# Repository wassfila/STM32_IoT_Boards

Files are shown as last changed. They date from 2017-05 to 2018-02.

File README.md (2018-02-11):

# STM32_IoT_Boards
* Expansion boards, PCB designs with STM32 chips.
* firmware running mbed-os
* simplest mesh ever with c++ driver libraries, rf-mesh lib using an nrf24l01+ lib

# Progress
* PCBs are under test
* 24 PIO ULN on/off test successfull
* Still no noticed design issues
* Current struggle with the PA3,PA2 ports that do not output the PWM as configured for a default UART
* Sensors node already working fine as an RF-Dongle (sensors not tested yet)
* Soldering order of nrf and bluepill is very important !!! Soldering order strategy required as it is double sided board.

# Git Submodules
* Still struggling with submodules, do not forget either of recursive clone, or manual add of submodule for pilibs

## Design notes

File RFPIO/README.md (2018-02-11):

# design_pcb_eagle

# firmware
* STM32 
* Bluepill as target
* mbed-os

# picpp_control
* Raspberry pi c++ control code that communicates with the Dongle firmware (not this one, rather the one under RFNode) through serial port
* This firmware is expecting RF messages coming from a dongle

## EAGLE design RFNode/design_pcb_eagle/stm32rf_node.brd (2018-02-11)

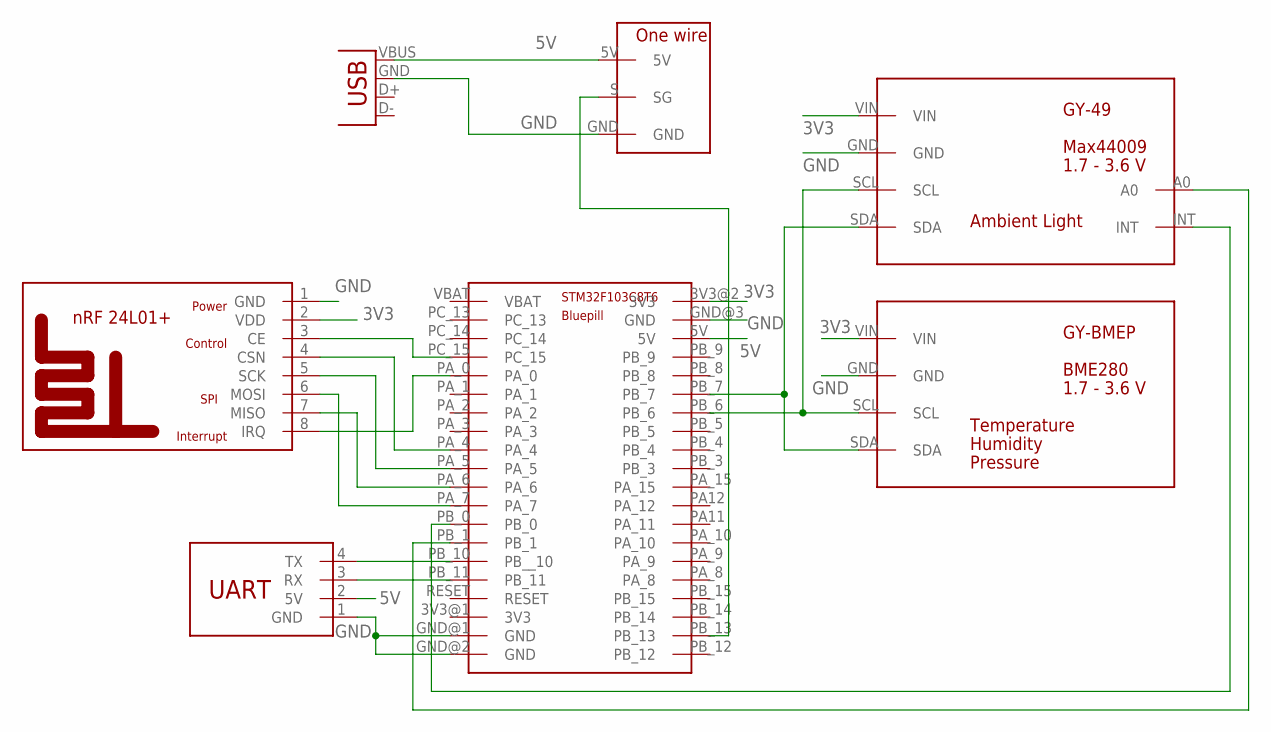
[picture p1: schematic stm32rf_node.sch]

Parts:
U$1: STM32_BLUEPILL
U$2: NRF24L01+REFDESIGNMINI; NRF24L01+REFDESIGN-MINI
U$3: GY-BMEPGY-BMEP-NOHOLE; GY-BMEP-NOHOLE
U$4: GY-49G-49-SURF; GY-49-SURF
U$5: ONE_WIRE'RIGHT'; ONE_WIRE_RIGHT
U$6: UARTMINI; UART-MINI
X1: USB-A-H

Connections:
3V3: U$1.3V3@2 (3V3), U$2.2 (VDD), U$3.VIN, U$4.VIN
5V: U$1.5V, U$5.5V, U$6.2 (5V), X1.VBUS (GND)
GND: U$1.GND@1 (GND), U$1.GND@2 (GND), U$1.GND@3 (GND), U$2.1 (GND), U$3.GND, U$4.GND, U$5.GND, U$6.1 (GND), X1.GND (VBUS)
INT: U$1.PB_0, U$4.INT
unnamed: U$1.PA_7, U$2.6 (MOSI)
unnamed: U$1.PA_6, U$2.7 (MISO)
unnamed: U$1.PA_5, U$2.5 (SCK)
unnamed: U$1.PA_4, U$2.4 (CSN)
unnamed: U$1.PB_1, U$4.A0
unnamed: U$1.PA_0, U$2.8 (IRQ)
unnamed: U$1.PB_10 (PB__10), U$6.4 (TX)
unnamed: U$1.PB_11, U$6.3 (RX)
unnamed: U$1.PB_6, U$3.SCL, U$4.SCL
unnamed: U$1.PB_7, U$3.SDA, U$4.SDA
unnamed: U$1.PC_15, U$2.3 (CE)
unnamed: U$1.PB_13, U$5.S (SG)

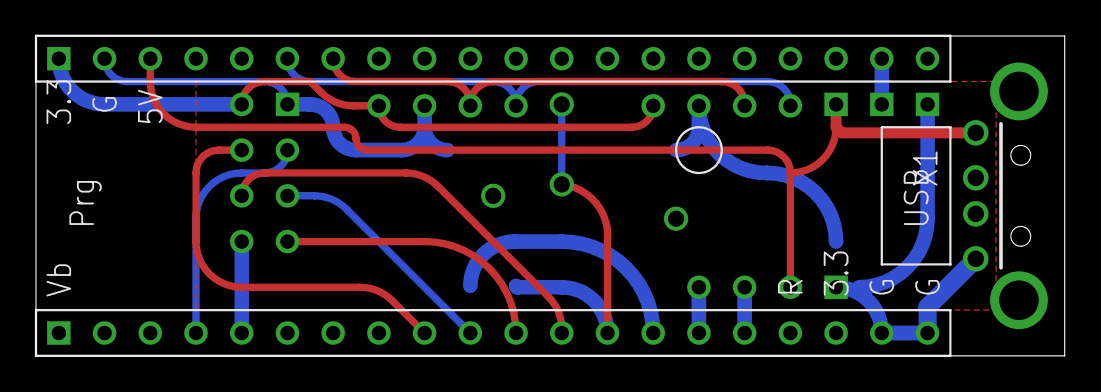
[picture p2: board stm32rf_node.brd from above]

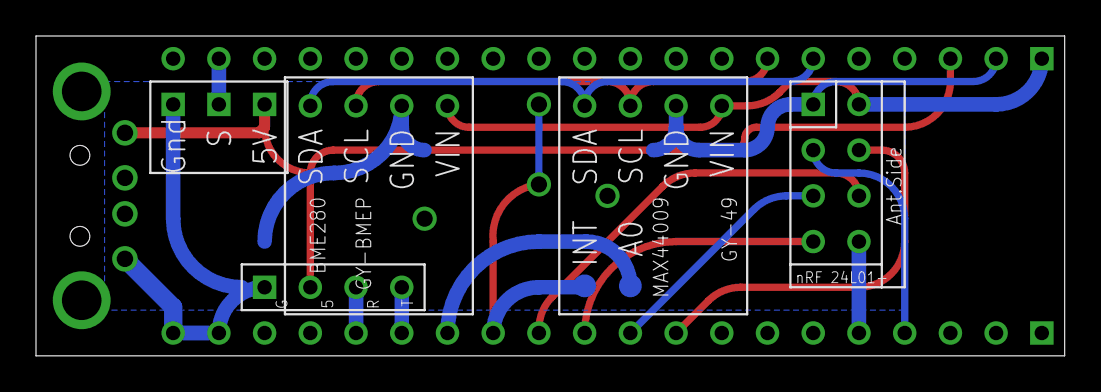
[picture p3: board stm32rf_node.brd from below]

Board: 2 copper layers, 57.1 x 17.8 mm, 7 parts (5 on the bottom side), 16 nets.

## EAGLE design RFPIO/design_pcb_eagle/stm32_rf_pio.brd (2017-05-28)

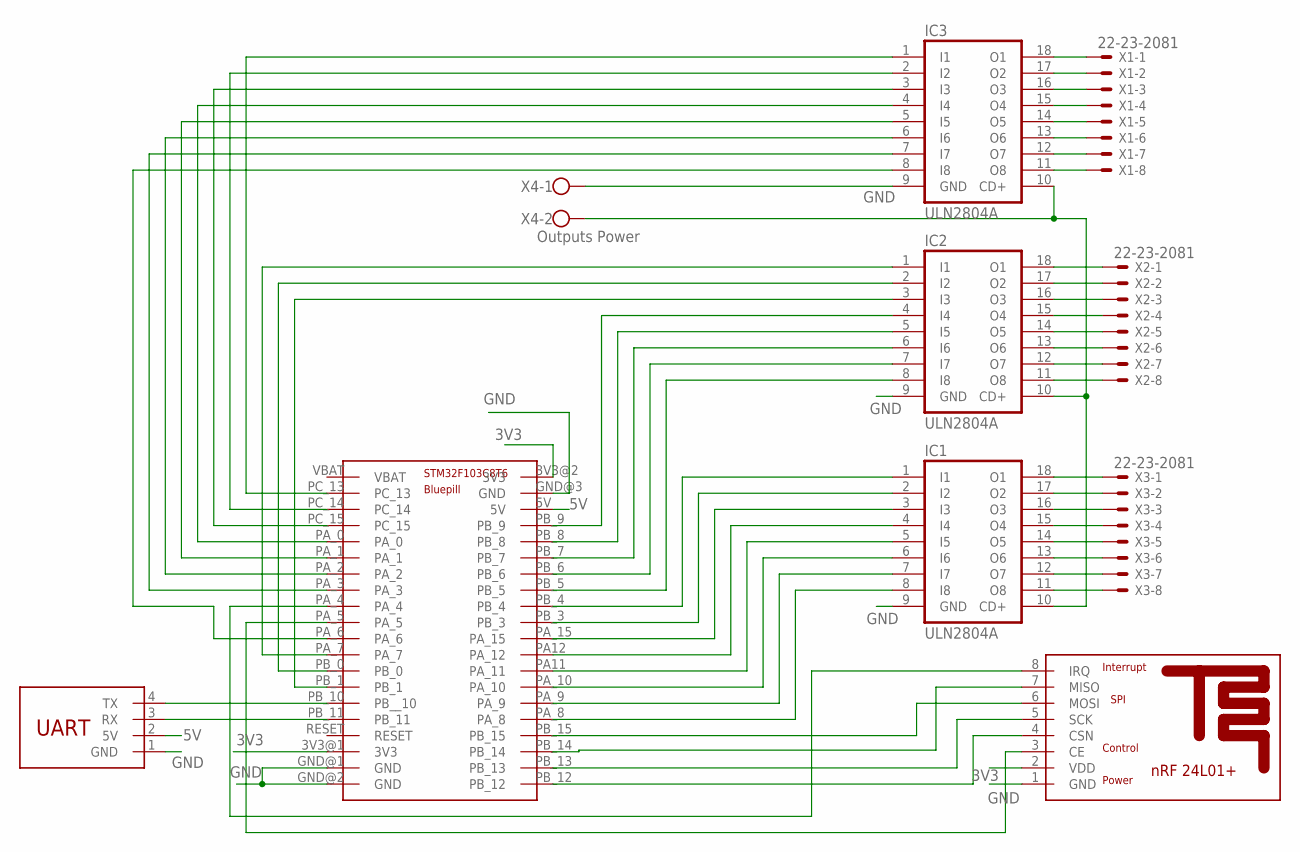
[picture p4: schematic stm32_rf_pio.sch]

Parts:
IC1, IC2, IC3: ULN2804A; DIL18
U$1: STM32_BLUEPILL
U$2: NRF24L01+REFDESIGNMINI; NRF24L01+REFDESIGN-MINI
U$3: UARTMINI; UART-MINI
X1, X2, X3: 22-23-2081
X4: Outputs Power; W237-102

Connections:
3V3: U$1.3V3@1 (3V3), U$1.3V3@2 (3V3), U$2.2 (VDD)
5V: U$1.5V, U$3.2 (5V)
A12: IC1.4 (I4), U$1.PA12 (PA_12)
GND: IC1.9 (GND), IC2.9 (GND), IC3.9 (GND), U$1.GND@1 (GND), U$1.GND@2 (GND), U$1.GND@3 (GND), U$2.1 (GND), U$3.1 (GND), X4.1
HV: IC1.10 (CD+), IC2.10 (CD+), IC3.10 (CD+), X4.2
M11: IC1.8 (I8), U$1.PA_8
M12: IC1.7 (I7), U$1.PA_9
M13: IC1.6 (I6), U$1.PA_10
M14: IC1.5 (I5), U$1.PA11 (PA_11)
M21: IC1.3 (I3), U$1.PA_15
M22: IC1.2 (I2), U$1.PB_3
M23: IC3.6 (I6), U$1.PA_2
M24: IC3.7 (I7), U$1.PA_3
M31: IC1.1 (I1), U$1.PB_4
M32: IC2.8 (I8), U$1.PB_5
M33: IC2.2 (I2), U$1.PB_0
M34: IC2.3 (I3), U$1.PB_1
unnamed: U$1.PB_12, U$2.4 (CSN)
unnamed: U$1.PB_13, U$2.5 (SCK)
unnamed: U$1.PB_14, U$2.7 (MISO)
unnamed: U$1.PB_15, U$2.6 (MOSI)
unnamed: IC2.7 (I7), U$1.PB_6
unnamed: IC2.6 (I6), U$1.PB_7
unnamed: IC2.5 (I5), U$1.PB_8
unnamed: IC2.4 (I4), U$1.PB_9
unnamed: IC2.1 (I1), U$1.PA_7
unnamed: IC3.18 (O1), X1.1
unnamed: IC3.17 (O2), X1.2
unnamed: IC3.16 (O3), X1.3
unnamed: IC3.4 (I4), U$1.PA_0
unnamed: IC3.5 (I5), U$1.PA_1
unnamed: IC3.8 (I8), U$1.PA_6
unnamed: IC3.1 (I1), U$1.PC_13
unnamed: IC3.2 (I2), U$1.PC_14
unnamed: IC3.3 (I3), U$1.PC_15
unnamed: IC3.15 (O4), X1.4
unnamed: IC3.14 (O5), X1.5
unnamed: IC3.13 (O6), X1.6
unnamed: IC3.12 (O7), X1.7
unnamed: IC3.11 (O8), X1.8
unnamed: IC2.18 (O1), X2.1
unnamed: IC2.17 (O2), X2.2
unnamed: IC2.16 (O3), X2.3
unnamed: IC2.15 (O4), X2.4
unnamed: IC2.14 (O5), X2.5
unnamed: IC2.13 (O6), X2.6
unnamed: IC2.12 (O7), X2.7
unnamed: IC2.11 (O8), X2.8
unnamed: IC1.18 (O1), X3.1
unnamed: IC1.17 (O2), X3.2
unnamed: IC1.16 (O3), X3.3
unnamed: IC1.15 (O4), X3.4
unnamed: IC1.14 (O5), X3.5
unnamed: IC1.13 (O6), X3.6
unnamed: IC1.12 (O7), X3.7
unnamed: IC1.11 (O8), X3.8
unnamed: U$1.PA_4, U$2.8 (IRQ)
unnamed: U$1.PA_5, U$2.3 (CE)
unnamed: U$1.PB_10 (PB__10), U$3.4 (TX)
unnamed: U$1.PB_11, U$3.3 (RX)

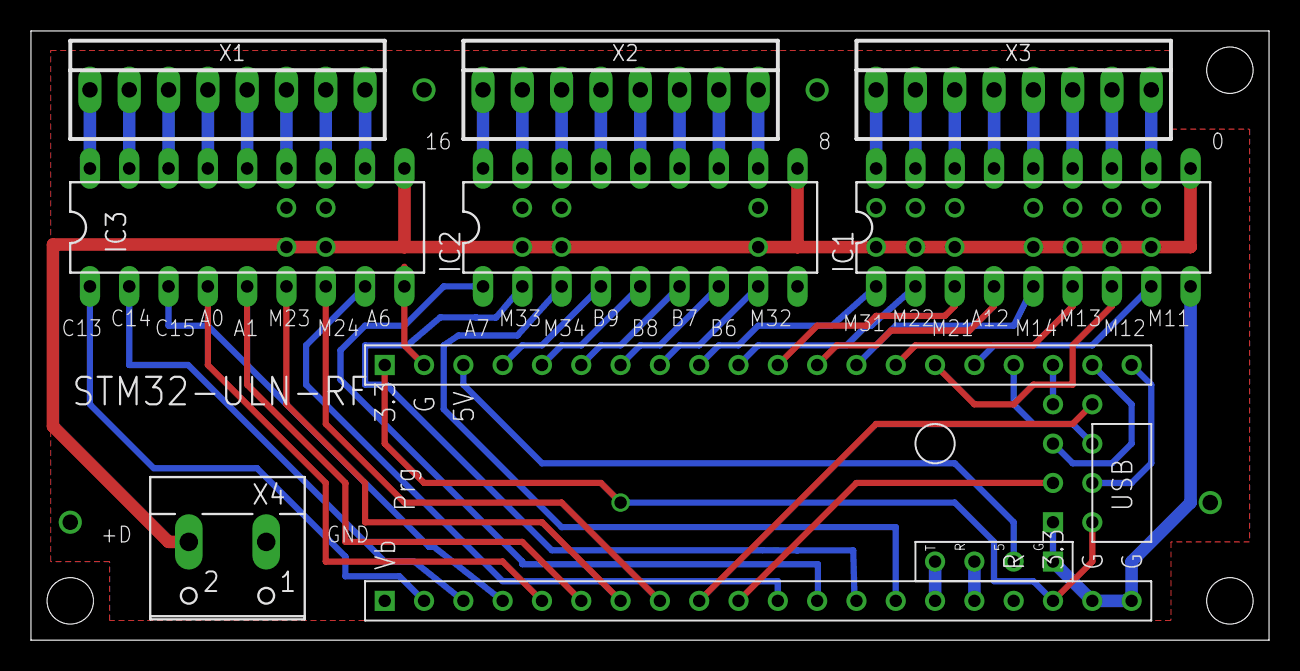
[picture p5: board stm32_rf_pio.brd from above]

Board: 2 copper layers, 80.0 x 39.4 mm, 10 parts (1 on the bottom side), 60 nets.

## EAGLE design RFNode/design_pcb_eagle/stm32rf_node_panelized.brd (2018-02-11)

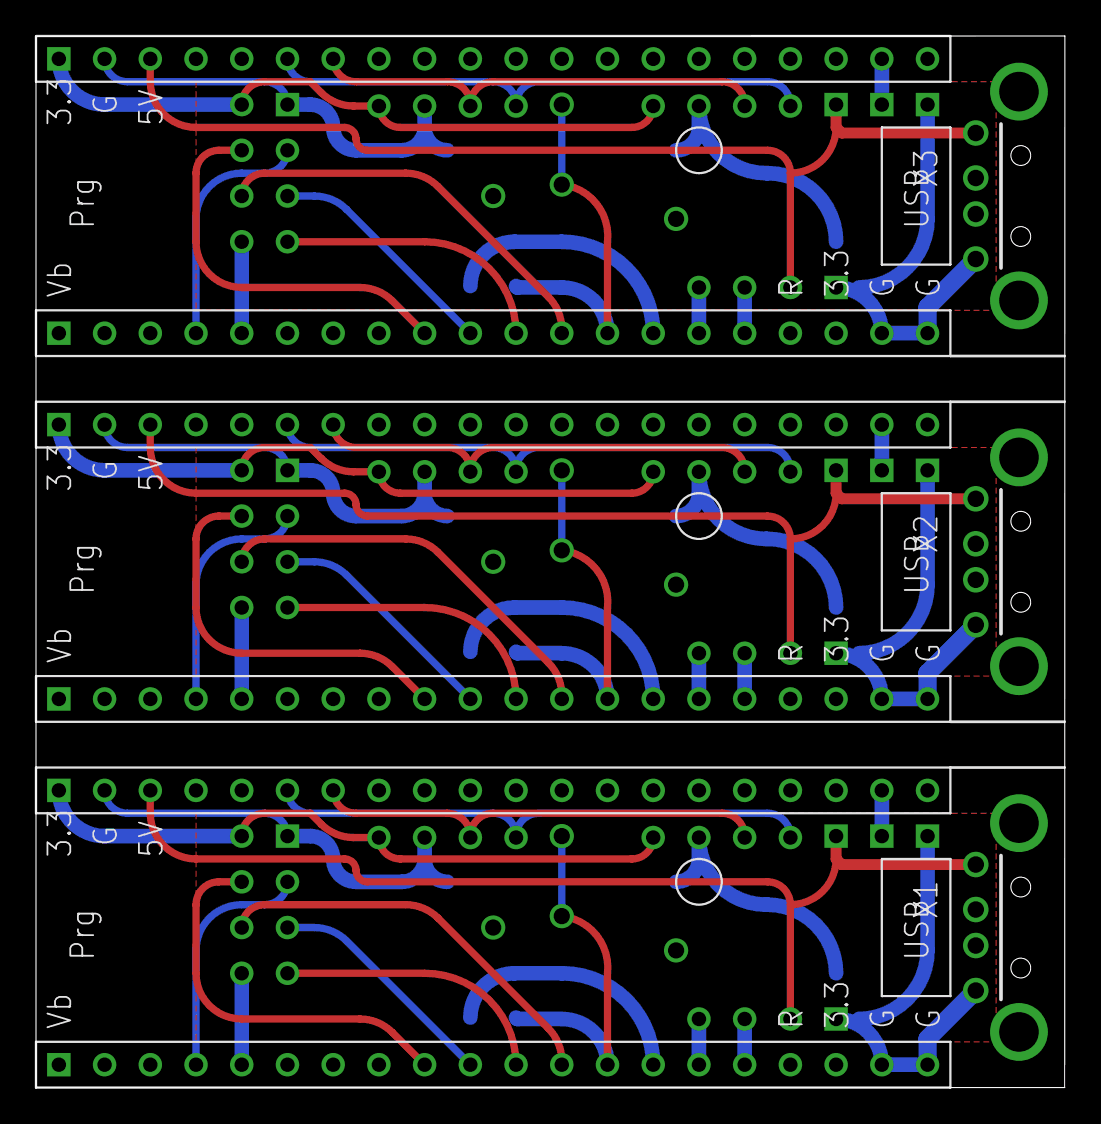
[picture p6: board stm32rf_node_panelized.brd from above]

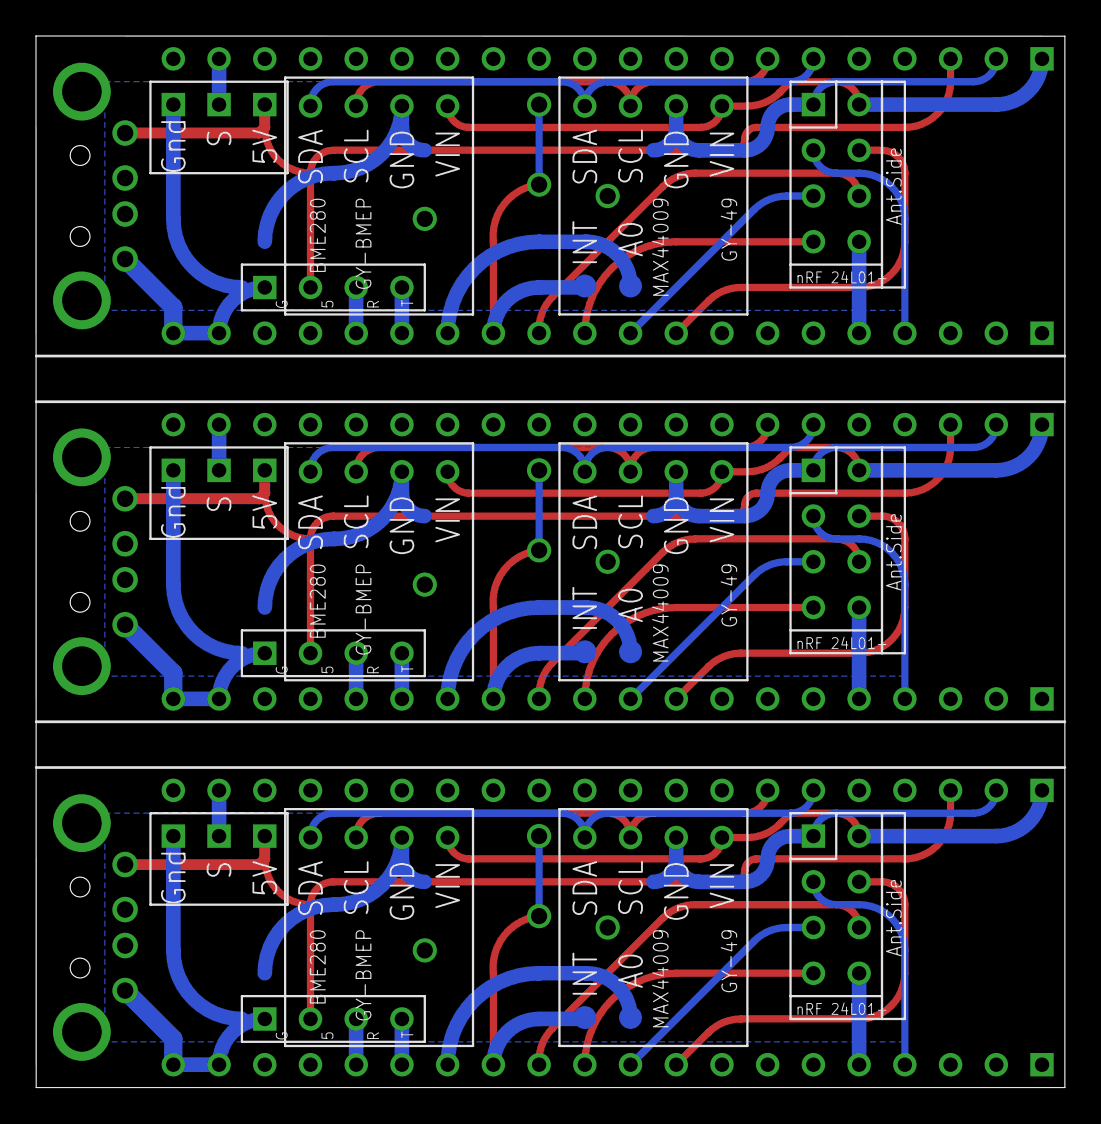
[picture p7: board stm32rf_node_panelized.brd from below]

Board: 2 copper layers, 57.2 x 58.4 mm, 21 parts (15 on the bottom side), 48 nets.

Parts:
U$1, U$7, U$13: STM32_BLUEPILL
U$2, U$8, U$14: NRF24L01+REFDESIGNMINI; NRF24L01+REFDESIGN-MINI
U$3, U$9, U$15: GY-BMEPGY-BMEP-NOHOLE; GY-BMEP-NOHOLE
U$4, U$10, U$16: GY-49G-49-SURF; GY-49-SURF
U$5, U$11, U$17: ONE_WIRE'RIGHT'; ONE_WIRE_RIGHT
U$6, U$12, U$18: UARTMINI; UART-MINI
X1, X2, X3: USB-A-H

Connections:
3V1: U$7.3V3@2, U$8.2, U$9.VIN, U$10.VIN
3V2: U$13.3V3@2, U$14.2, U$15.VIN, U$16.VIN
3V3: U$1.3V3@2, U$2.2, U$3.VIN, U$4.VIN
5V: U$1.5V, U$5.5V, U$6.2, X1.VBUS
5V1: U$7.5V, U$11.5V, U$12.2, X2.VBUS
5V2: U$13.5V, U$17.5V, U$18.2, X3.VBUS
GND: U$1.GND@1, U$1.GND@2, U$1.GND@3, U$2.1, U$3.GND, U$4.GND, U$5.GND, U$6.1, X1.GND
GND1: U$7.GND@1, U$7.GND@2, U$7.GND@3, U$8.1, U$9.GND, U$10.GND, U$11.GND, U$12.1, X2.GND
GND2: U$13.GND@1, U$13.GND@2, U$13.GND@3, U$14.1, U$15.GND, U$16.GND, U$17.GND, U$18.1, X3.GND
INT: U$1.PB_0, U$4.INT
INT1: U$7.PB_0, U$10.INT
INT2: U$13.PB_0, U$16.INT
unnamed: U$1.PA_7, U$2.6
unnamed: U$1.PA_6, U$2.7
unnamed: U$1.PA_5, U$2.5
unnamed: U$1.PA_4, U$2.4
unnamed: U$1.PB_1, U$4.A0
unnamed: U$1.PA_0, U$2.8
unnamed: U$1.PB_10, U$6.4
unnamed: U$1.PB_11, U$6.3
unnamed: U$1.PB_6, U$3.SCL, U$4.SCL
unnamed: U$1.PB_7, U$3.SDA, U$4.SDA
unnamed: U$1.PC_15, U$2.3
unnamed: U$1.PB_13, U$5.S
unnamed: U$7.PB_10, U$12.4
unnamed: U$7.PB_11, U$12.3
unnamed: U$7.PB_6, U$9.SCL, U$10.SCL
unnamed: U$7.PB_7, U$9.SDA, U$10.SDA
unnamed: U$7.PA_7, U$8.6
unnamed: U$7.PA_6, U$8.7
unnamed: U$7.PA_5, U$8.5
unnamed: U$7.PA_4, U$8.4
unnamed: U$7.PB_1, U$10.A0
unnamed: U$7.PA_0, U$8.8
unnamed: U$7.PC_15, U$8.3
unnamed: U$7.PB_13, U$11.S
unnamed: U$13.PB_10, U$18.4
unnamed: U$13.PB_11, U$18.3
unnamed: U$13.PB_6, U$15.SCL, U$16.SCL
unnamed: U$13.PB_7, U$15.SDA, U$16.SDA
unnamed: U$13.PA_7, U$14.6
unnamed: U$13.PA_6, U$14.7
unnamed: U$13.PA_5, U$14.5
unnamed: U$13.PA_4, U$14.4
unnamed: U$13.PB_1, U$16.A0
unnamed: U$13.PA_0, U$14.8
unnamed: U$13.PC_15, U$14.3
unnamed: U$13.PB_13, U$17.S

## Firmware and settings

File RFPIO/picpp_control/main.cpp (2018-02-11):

//for usleep
#include <unistd.h>
//for printf
#include <stdio.h>
//for stdout
#include <iostream>

//for abs
#include <cmath>

#include "joystick.hpp"
#include "serial.hpp"
#include "log.hpp"
#include "utils.hpp"


#define RESET   "\033[0m"
#define BLACK   "\033[30m"      /* Black */
#define RED     "\033[31m"      /* Red */
#define GREEN   "\033[32m"      /* Green */
#define YELLOW  "\033[33m"      /* Yellow */
#define BLUE    "\033[34m"      /* Blue */
#define MAGENTA "\033[35m"      /* Magenta */
#define CYAN    "\033[36m"      /* Cyan */
#define WHITE   "\033[37m"      /* White */
#define BOLDBLACK   "\033[1m\033[30m"      /* Bold Black */
#define BOLDRED     "\033[1m\033[31m"      /* Bold Red */
#define BOLDGREEN   "\033[1m\033[32m"      /* Bold Green */
#define BOLDYELLOW  "\033[1m\033[33m"      /* Bold Yellow */
#define BOLDBLUE    "\033[1m\033[34m"      /* Bold Blue */
#define BOLDMAGENTA "\033[1m\033[35m"      /* Bold Magenta */
#define BOLDCYAN    "\033[1m\033[36m"      /* Bold Cyan */
#define BOLDWHITE   "\033[1m\033[37m"      /* Bold White */
 
#define CLEAR "\033[2J"  // clear screen escape code 

//Axis 5 : 1520 - 1950 

void printf_tab(const char* data, int size)
{
	char line_print[400];
	sprintf(line_print,"0x %02x %02x %02x %02x %02x %02x %02x\n",data[0],data[1],data[2],data[3],data[4],data[5],data[6]);
	std::string line(line_print);
	Log::cout << line << Log::Info();
}

void printf_tab2(const char* data, int size)
{
	char line_print[400];
	sprintf(line_print,"0x %02x %02x\n",data[0],data[1]);
	std::string line(line_print);
	Log::cout << line << Log::Info();
}

void MapAxis(JAxis &axis,char s_id,Serial&ser)
{
	if(axis.isUpdated())
	{
		int val = 10000*(axis.getValue()+1)/2;//[-1,+1] => [0, 1]
		uint8_t data[7];
		data[0] = 5;	//size is 5
		data[1] = 'S';	//Protocol 'Servos'
		data[2] = s_id;	//Servo Id = '1'
		data[3] = val / 256;	//16 bit val
		data[4] = val % 256;
		printf_tab2((const char*)&data[3],2);
		utl::crc_set(data);
		//printf_tab((const char*)data,7);
		ser.send((const char*)(data),5+2);
	}
}

void TestCom(Serial&ser)
{
	int val = 55555;//[-1,+1] => [0, 1]
	uint8_t data[7];
	data[0] = 5;	//size is 5
	data[1] = 4;	//Protocol 'Servos'
	data[2] = 1;	//Servo Id = '1'
	data[3] = 0x55;	//16 bit val
	data[4] = 0x44;
	//printf_tab2((const char*)&data[3],2);
	utl::crc_set(data);
	printf_tab((const char*)data,7);
	ser.send((const char*)(data),5+2);
}

void set_pios(Serial&ser, int val)
{
	uint8_t data[7];
	data[0] = 5;	//size is 5
	data[1] = 'P';	//Protocol 'PIOs'
	data[2] = val & 0xFF;
	data[3] = (val>>8) & 0xFF;
	data[4] = (val>>16) & 0xFF;
	utl::crc_set(data);
	printf_tab((const char*)data,7);
	ser.send((const char*)(data),5+2);
}



int main( int argc, char** argv ) 
{
	std::cout << "______________________Config______________________" << std::endl;
	strmap conf;
	utl::args2map(argc,argv,conf);//here is checked './configfile.txt'

	Log::config(conf);

	Serial 			ser(conf);	// - process serial port stream

	Joystick 	joy;
	
	//joy.start("/dev/input/js0");
	
	//std::cout << MAGENTA << "Colored " << CYAN << "Text" << RESET << std::endl;
	
	usleep(1000000);
	set_pios(ser,0x00FFFFFF);
	usleep(1000000);
	set_pios(ser,0x00000000);

	while (1) 
	{
		std::cout << RESET;
		//display Received log
		if(ser.update())
		{
			ser.processBuffer();
			ser.logBuffer();//log received line
		}
		usleep (10000);
		
	}

	return 0;
}

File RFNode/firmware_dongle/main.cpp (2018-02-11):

#include "mbed.h"

#include "rfmesh.h"
#include "Servo.h"
#include "suart.h"

#define BOARD_IS_RF_DONGLE 1

Serial   rasp(PB_10, PB_11, 115200);
DigitalOut myled(PC_13);
Ticker tick_call;
//nRF Modules 1:Gnd, 2:3.3v, 3:ce,  4:csn, 5:sck, 6:mosi, 7:miso, 8:irq 
#if BOARD_IS_RFPIO == 1
//RfMesh mesh(&rasp,           PA_5,  PB_12, PB_13, PB_15, PB_14, PA_4);
#elif BOARD_IS_RF_DONGLE ==1
RfMesh mesh(&rasp,           PC_15, PA_4, PA_5,   PA_7,  PA_6,    PA_0);
#endif

suart com(&rasp);

void the_ticker()
{
    myled = !myled;
    
}

bool got_message = false;
uint8_t payload[32];

void uart_message_received(uint8_t *data)
{
    //rasp.printf("stm32_dongle> OK message received with %d Bytes\n",data[0]);
    uint8_t size = data[0];
    for(int i=0;i<size;i++)
    {
        payload[i] = data[i];
    }
    got_message = true;
}

void rf_message_received(uint8_t *data,uint8_t size)
{
    //rasp.printf("stm32_dongle>rf> Rx message (%d bytes) unused in dongle\n",size);
    rasp.printf("RX(%d)> ",size);
    for(int i=0;i<size;i++)
    {
        rasp.printf("0x%0x ",data[i]);
    }
    rasp.printf("\n");
}

void init()
{
    rasp.printf("stm32_dongle> Hello PIO Dongle\n");

    tick_call.attach(&the_ticker,1);

    mesh.init();//left to the user for more flexibility on memory management

    mesh.nrf.selectChannel(2);

    mesh.attach(&rf_message_received,RfMesh::CallbackType::Message);

    com.attach(uart_message_received);

}

int main() 
{
    init();

    while(1) 
    {
        wait_ms(1);
        if(got_message)
        {
            //rasp.printf("stm32_dongle> start transmission\n");
            mesh.nrf.start_transmission(payload,payload[0]);
            got_message = false;
        }
    }
}

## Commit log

2017-04-23 First versions of the IoT boards
    [stm32_rf_pio.brd, stm32_rf_pio.sch, stm32rf_node.brd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]
2017-04-23 Added connections for servo motors with Gnd-HV-Signal for all pwm outputs
    [stm32_rf_pio.brd, stm32_rf_pio.sch]
2017-04-23 gnd with rastnet
    [stm32_rf_pio.brd]
2017-04-24 rounting step 1
    [stm32rf_node.brd, stm32rf_node.sch]
2017-04-24 done routing with gnd rastnet
    [stm32rf_node.brd, stm32rf_node.sch]
2017-05-06 Added possibility to connect the MPU 6050 on the I2C by shifting connections to match Add with Gnd
    [stm32rf_node.brd, stm32rf_node.sch]
2017-05-07 preparing production 1
    [stm32_rf_pio.brd, stm32rf_node.brd]
2017-05-07 First produced version
    [stm32_rf_pio.GBL, stm32_rf_pio.GBO, stm32_rf_pio.GBP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]
2017-05-07 First Production with Panel
    [Combined_PIO_Node.GBL, Combined_PIO_Node.GBO, Combined_PIO_Node.GBP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]
2017-05-28 updated board
    [stm32_rf_pio.brd, stm32_rf_pio.sch]
2017-05-28 rename restructure creation of new projects ...
    [Combined_PIO_Node.GBL, Combined_PIO_Node.GBO, Combined_PIO_Node.GBP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]
2017-05-28 updated wrog merge after move
    [stm32_rf_pio.brd, stm32_rf_pio.sch]
2017-05-28 first working full pio chain
2017-05-31 renaming project for split pio servos
2017-05-31 new project specific for servos
2017-06-01 adapted to servos but only 10 work
2017-06-03 testing servos 11,12
2017-09-17 servo fix and rf protocol with CRC
    [main.cpp]
2018-02-11 new production with usb connector
    [stm32rf_node.GBL, stm32rf_node.GBO, stm32rf_node.GBP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]
